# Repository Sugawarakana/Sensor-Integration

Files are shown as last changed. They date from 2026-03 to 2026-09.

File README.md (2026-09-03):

# Integrated Sensor Board for Battery Off-Gas Monitoring

A compact PCB and firmware stack that integrates multiple gas sensors and a battery off-gas detector onto one board, developed as part of a collaborative research project between the **University of Michigan**, **Universitat Politecnica Valencia**, and **UL Research Institutes**. The board targets applications in **battery safety**, **robotics**, and **energy storage system** environments where real-time multi-gas monitoring in constrained spaces is critical.

## Project Overview

The board consolidates multiple commerically-available gas sensors that detect hydrogen (H₂), carbon monoxide (CO), carbon dioxide (CO₂), volatile organic compounds (VOC), methane (CH₄), and electrolyte-vapor onto a single PCB, interfacing through **two independent CAN buses**, **I²C**, and an **analog ADC** channel. The controller is an **STM32 Nucleo-G431KB**, chosen for its native FDCAN peripheral, I²C support, and 12-bit ADC.

Since the Nucleo-G431KB has only one CAN controller, the two buses run at different bit rates on different hardware:

- **FDCAN1 @ 500 kbps** — Telaire T3650 and SGX-BLD2, through an on-board CAN transceiver.
- **MCP2515 @ 250 kbps** (SPI) — Li-ion Tamer, which requires its own 250 kbps segment.

The project spans: **PCB design** (Autodesk Eagle), **embedded firmware** ([OffgasMonitor.ino](OffgasMonitor/OffgasMonitor.ino), with non-blocking dual-CAN, dual-sensor I²C and ADC acquisition, byte-level protocol decoding, and on-chip health monitoring), and a **Python data-acquisition pipeline** ([serial_logger.py](OffgasMonitor/serial_logger.py), with serial parsing into a wide-table CSV).

## Specifications

| Parameter | Detail |
|---|---|
| **Controller** | STM32 Nucleo-G431KB (ARM Cortex-M4) |
| **Layers** | 1-layer PCB |
| **Board Thickness** | 1.6 mm (JLCPCB default) |
| **Power Supply** | 12 V battery input via terminal blocks |
| **Communication** | FDCAN1 (500 kbps), MCP2515 CAN (250 kbps) over SPI, I²C (100 kHz), analog ADC |
| **Log Rate** | 1 Hz (`LOG_INTERVAL = 1000 ms`) |
| **Serial** | 115200 baud |
| **Fabrication** | JLCPCB |

## Sensor Summary

| Sensor | Measurement | Interface | Address / ID | Power |
|---|---|---|---|---|
| Telaire T3650 | H₂, pressure, humidity, temperature | FDCAN1 @ 500 kbps | `0x18FF0CEB` (J1939, ext.) | 12 V direct |
| SGX-BLD2 | H₂ %, CO level, status flags | FDCAN1 @ 500 kbps | `0x256` (standard) | 12 V direct |
| Li-ion Tamer | Electrolyte-vapor off-gas, state, temperature | CAN @ 250 kbps via MCP2515 (SPI) | PGN `0xFF01` (J1939, ext.) | 12 V direct |
| MiCS-VZ-89TE | CO₂-equivalent & VOC | I²C | — | 3.3 V (Nucleo output) |
| MP7227 | CH₄ (methane) | Analog → ADC (`A0`) | — | 3.0 V (MIC5233 LDO) |
| SEN66 | PM1.0/2.5/4.0/10, RH, T, VOC & NOx index, NDIR CO₂ | I²C @ 100 kHz | `0x6B` | 3.3 V (buck from 12 V) |

> **Note:** the MiCS-VZ-89TE CO₂ figure is a CO₂-*equivalent* derived from its VOC channel, not a real CO₂ measurement. The SEN66 carries the true NDIR CO₂ reading; both are logged side by side (`co2_ppm` vs `sen66_co2_ppm`).

## Power Architecture

```
12V Supply
  │
  ├──[Terminal Blocks]──► Telaire T3650 (H₂)      — 12V direct
  ├──[Terminal Blocks]──► SGX-BLD2 (CO/H₂)        — 12V direct
  ├──[CAN Terminal]─────► Li-ion Tamer (off-gas)  — 12V direct
  │
  ├──► Buck regulator ──► 3.3V ──► SEN66 (PM/RH/T/VOC/NOx/CO₂)
  │
  └──► Buck regulator ──► 5V ──► Nucleo-G431KB (onboard regulator)
                                  └──► 3.3V ──► MiCS-VZ-89TE (CO₂ & VOC)
                                  └──► 3.3V ──► MIC5233 LDO ──► 3.0V ──► MP7227 (CH₄)
```

The SEN66 runs from its own buck rail rather than the Nucleo's 3.3 V output: its fan and
heater draw far more than the on-board regulator can supply. Only its I²C lines and ground
are shared with the MCU.

## Signal Chain

- **Telaire T3650 & SGX-BLD2:** CAN → on-board transceiver → **FDCAN1 @ 500 kbps** → MCU.
- **Li-ion Tamer:** CAN @ **250 kbps** → **MCP2515** controller → **SPI1** → MCU.
- **MiCS-VZ-89TE:** **I²C** directly to the MCU.
- **SEN66:** **I²C** to the MCU, sharing the bus with the MiCS-VZ-89TE. The bus is clamped to **100 kHz** (`Wire.setClock(100000)`) — that is the SEN66's ceiling, and the MiCS is comfortable at that rate.
- **MP7227 (CH₄):** analog output → zeroed via potentiometer → amplified (ADA4528 precision op-amp stage with HF filtering) → **ADC** (`A0`, 12-bit). Sensor rail from the **MIC5233** LDO.

### Li-ion Tamer → Power / CAN bus

| Li-ion Tamer pin | Connects to | Target terminal | Notes |
|---|---|---|---|
| Vin | PCB | 12 V (CAN terminal) | Supply positive |
| GND | PCB | GND (CAN terminal) | Supply / common ground |
| CANH | MCP2515 module | CANH | CAN differential high |
| CANL | MCP2515 module | CANL | CAN differential low |

### MCP2515 → Nucleo (SPI)

| MCP2515 pin | Nucleo pin | Type | Notes |
|---|---|---|---|
| SCK (18) | `PB3` / D13 | SPI clock | SPI1 default |
| MOSI (19) | `PB5` / D11 | Master out, slave in | SPI1 default |
| MISO (16) | `PB4` / D12 | Master in, slave out | SPI1 default |
| CS (20) | `PA8` / **D9** | Chip select | D9 instead of the default D10, which is `fdcan1_rx` |
| INT (21) | `PB0` / **D3** | Interrupt input | D3 instead of the default D2, which is `fdcan1_tx` |
| VCC / GND | 3V3 / GND | Power | Shared ground with the CAN terminal ground |
| RST | NRST | Reset | Pull-up reset |
| — | CAN ground | Power | GND (CAN terminal) |

The MCP2515 module runs from a **16 MHz** crystal (`QUARTZ_FREQUENCY`); the firmware prints whether the requested 250 kbps is an exact bit rate at boot.

## Design Highlights

- **Sensor placement:** all gas inlets sit along the board edges to maximize exposure and airflow.
- **Unidirectional signal flow:** voltage and signal routing follows a single direction across the board for a clean layout and easy debugging.
- **Ground stability:** a large copper pour provides a solid ground plane and minimizes ground bounce.
- **Filtering:** decoupling capacitors and filtering suppress high-frequency noise on power and signal lines.
- **Differential pair integrity:** CANH/CANL pairs are routed with controlled impedance and matched length.
- **Mechanical:** mounting holes for integration into enclosures or test fixtures.

## Firmware — `OffgasMonitor/OffgasMonitor.ino`

A single non-blocking acquisition loop that services two CAN buses, two I²C sensors, and the ADC, then emits one human-readable report per second.

### Architecture

- **Continuous CAN polling.** `pollAllCan()` drains both receive FIFOs completely on every loop iteration, so neither bus backs up while the report is being printed. It is called again immediately after `logData()` to catch frames that arrived during printing.
- **Non-blocking SEN66 startup.** `setup()` only issues the `deviceReset()`; the 1.2 s settling time, the `startContinuousMeasurement()` call, and the 1.1 s first-frame delay are stepped through by a `SEN66_RESET → SEN66_WAIT → SEN66_RUN` state machine inside `pollSen66()`, so no `delay()` ever stalls the CAN buses. A failed start is simply retried on the next 1.2 s tick.
- **Drift-free I²C sampling.** In `SEN66_RUN` the read deadline advances by a fixed `SEN66_PERIOD_MS` rather than reloading from `millis()`, so the sampling instant does not creep with the ~100 ms `logData()` spends on serial output; it resyncs only if it falls more than a full period behind. One read is ~2–3 ms of bus traffic at 100 kHz — short enough for the 32-slot FDCAN FIFO and the interrupt-driven MCP2515 buffer to absorb whatever arrives meanwhile.
- **Latest-frame slots.** Each CAN device gets a `Latest<T>` slot holding the most recent frame of the current cycle plus a `valid` flag. The flag is cleared after every report, so **a device that stays silent for a second leaves its section out of the output entirely** — silence is preserved as a diagnostic rather than being masked by stale data.
- **Age-based staleness for the SEN66.** The SEN66 deliberately does *not* use a `Latest<>` slot. It produces exactly one frame per second — the same rate as the log cycle — so a clear-every-cycle flag would make its block blink in and out as the two 1 Hz clocks drift past each other. Instead the last sample is kept with its `millis()` timestamp and reported with a `STALE` status once it ages past `SEN66_STALE_MS` (2.5 s), which points at I²C or power rather than at normal jitter.
- **CAN polling during ADC averaging.** `readAvgPolled()` averages 16 ADC samples to suppress noise; the ~200 µs settling gap between samples is spent polling CAN instead of idling. Averaging 16 samples across 2 channels takes ≈ 6.4 ms, which is too long to leave the buses unattended.
- **Rollover-safe scheduling.** The 1 Hz cadence uses a signed `millis()` comparison against `g_nextLog`, so it survives the 49-day `millis()` rollover, and the deadline advances by a fixed `LOG_INTERVAL` rather than from "now" to avoid drift.
- **Boot markers.** Setup prints tagged progress lines `A: boot` → `G: setup done` (`A` serial, `B` FDCAN1, `C` MCP2515, `D` I²C/ADC, `E` SEN66 reset + serial number, `F` die-temp calibration constants, `G` done), giving both a human and the Python logger an unambiguous reboot marker.

### Decoding

- **SGX-BLD2 (`0x256`)** — temperature (offset −55 °C), H₂ % (16-bit, ×0.01), an 8-bit status byte decoded bit-by-bit into named faults, supply voltage, humidity, roll counter, and CO level.
- **Telaire T3650 (`0x18FF0CEB`)** — pressure (16-bit LE, ×0.0078125 − 250 kPa), humidity (×0.4 %), H₂ concentration (×0.0025 %), temperature (×0.03125 − 273 °C), and a raw status byte.
- **Li-ion Tamer (PGN `0xFF01`)** — J1939 source address from the low ID byte, state (`Illegal / Error / Warmup / Normal / Alarm`), signed temperature, and a signed 16-bit off-gas scalar (÷100). The report is annotated `<<< ALARM` in the Alarm state, or flagged when the scalar reaches the alarm trigger level of 1.0.
- **SEN66 (I²C `0x6B`)** — PM1.0 / PM2.5 / PM4.0 / PM10 (µg/m³), relative humidity, temperature, VOC index, NOx index, and NDIR CO₂, read through the Sensirion float API.
- **Unknown frames** on either bus are captured and printed with bus name, ID, and raw data bytes, so an unexpected node on the wire is visible instead of silently dropped.

### SEN66 "unknown value" handling

The Sensirion float API divides each raw 16-bit word by its scale factor, so an unavailable channel surfaces as a plausible-looking number rather than `NaN`: `0xFFFF / 10 = 6553.5` for PM, `0x7FFF / 100 = 327.67` for RH/T, `0x7FFF / 10 = 3276.7` for the gas indices, and `0xFFFF` for CO₂. `printSen66Value()` compares against those sentinels and prints **`n/a`**, so a dead channel can never be mistaken for a real 6553.5 µg/m³ or 3276.7 index reading. Two status lines qualify the block further:

| Line | Meaning |
|---|---|
| `SEN66: no valid frame yet (starting up / running)` | Printed instead of the whole block; no frame has ever been read |
| `SEN66 Status:  gas index warming up` | VOC or NOx index still reads a hard 0 — VOC settles toward 100 over tens of seconds, NOx toward 1 after ~10–15 s |
| `SEN66 Status:  STALE, frame age <n> ms` | The cached frame is older than 2.5 s — check I²C wiring and the 3.3 V buck rail |

### Board health monitoring

Each cycle also reports the MCU's own condition using the internal channels and STM32G4 factory calibration constants:

1. **Actual VDDA** is back-computed from the internal reference (`VREFINT_CAL` at 3.0 V) — the reference voltage is fixed, so a lower reading implies a higher supply.
2. **Junction temperature (Tj)** is derived by normalizing the temperature-sensor reading to the 3.0 V calibration reference and interpolating between the factory `TS_CAL1` (30 °C) and `TS_CAL2` (130 °C) points.
3. Running **max Tj** and **min VDDA** are tracked across the whole run, and the status line reports `OK` / `HIGH` (> 60 °C) / `OVERHEAT` (> 85 °C).

Tj is die temperature, not ambient, and factory calibration is only accurate to roughly ±5 °C — it is a "is the board cooking?" check, not an ambient-temperature log.

### Serial output format

One block per second, sections separated by `=============================`. Each round begins with `Raw ADC Value:`, which the Python logger uses as the round boundary:

```
Raw ADC Value: 2048
Voltage: 1.650 V
=============================
Board health (STM32G431KB):
Die Temp:           42.3 C
Die Temp Max:       44.1 C
VDDA:               3298 mV
VDDA Min:           3290 mV
ADC raw (ts/vref):  1035/1512
Board Status:       OK
=============================
CO2 equ(ppm): 412 ppm
VOC(isobutylene) equ: 87 ppb
=============================
Message received from SEN66:
PM1.0:              0.0 ug/m3
PM2.5:              0.0 ug/m3
PM4.0:              0.0 ug/m3
PM10:               0.0 ug/m3
Humidity:           54.5 %
Temperature:        25.38 C
VOC Index:          0.0
NOx Index:          0.0
CO2:                431 ppm
SEN66 Status:       gas index warming up
=============================
Message received from SGX-BLD2:
...
=============================
Message received from Telaire T3650:
...
=============================
Message received from Li-ion Tamer:
Tamer SA=0xEB  State=Normal  Temp=24C  OffGas=0.12
=============================
```

## Host Data Acquisition — `OffgasMonitor/serial_logger.py`

A dependency-light (`pyserial` only) logger that parses the live serial stream and aggregates each one-second round into a single wide-table CSV row.

```bash
pip install pyserial

python serial_logger.py                 # use the PORT default in the file (COM3)
python serial_logger.py COM3            # specify the port
python serial_logger.py /dev/ttyACM0
python serial_logger.py --list-ports    # list available ports
python serial_logger.py --auto          # auto-pick a port that looks like an STM32
python serial_logger.py --selftest      # no hardware needed; verify parsing on built-in samples
```

| Flag | Effect |
|---|---|
| `--baud` | Baud rate (default 115200) |
| `--prefix` | Output filename prefix (default `sensor_log`; the start time is appended) |
| `--auto` | Pick the STMicroelectronics VID/description port automatically |
| `--list-ports` | List ports and exit |
| `--no-raw` | Skip the timestamped raw-text `.log` alongside the CSV |
| `--no-reconnect` | Exit on a dropout instead of retrying every 2 s |
| `--quiet` | Do not echo each row to the console |
| `--selftest` | Run the parser over built-in samples and check every field |

### Behavior

- **Section state machine.** The firmware reuses labels across sections (`Voltage:` appears under both ADC and SGX; `Temperature:` / `Humidity:` under SGX, Telaire *and* SEN66), so the parser disambiguates by *which section it is currently in*; a separator line clears the section and prevents bleed-over. Two label collisions are handled explicitly: `VOC(` anchors the MiCS reading so the SEN66's `VOC Index:` cannot overwrite it, and the colon in `SEN66:` distinguishes the no-frame one-liner from the in-block `SEN66 Status:` line.
- **Numbers are read after the last colon.** `num()` only searches the tail of a line, so digits inside a label — the 2 in `CO2`/`H2`, the 1.0 in `PM1.0` — are never mistaken for the reading. A channel printed `n/a` contains no digits and therefore lands as an empty cell.
- **Empty means silent.** ADC, board health, and I²C columns are populated every round. If one of the CAN devices sent nothing that second, its columns are left **empty on purpose** — that emptiness is the record that the device was offline, so it must not be forward-filled in post-processing. The `can_device` column lists which devices were heard from that round.
- **Empty SEN66 columns mean something else.** Because the SEN66 is on I²C, its block is present every round once running, so blank value columns are a fault rather than a silent bus. `sen66_status` says which: `NO_FRAME` (not started yet), `WARMUP` (gas-index algorithm not converged), or `STALE` with `sen66_age_ms` giving the age of the cached frame. Statuses accumulate semicolon-separated, since the firmware can print more than one in a round.
- **Fault flags reassembled.** Individual SGX flag lines are collected into a semicolon-separated `sgx_flags` list *and* re-packed into `sgx_flags_hex` for easy comparison.
- **Crash-safe.** Every row is flushed to disk immediately, a Ctrl+C or serial dropout still writes the in-progress round, the port is reconnected automatically after a dropout, and board reboots (`A: boot`) are counted and reported at exit.
- **Self-test.** `--selftest` runs the parser against embedded sample output covering the normal case, an overheat + fault-flag + Tamer-alarm case, a stale SEN66 frame with an `n/a` CO₂ channel, unknown frames on both buses, and a truncated final round holding only the SEN66 no-frame one-liner — then writes `selftest_output.csv`. It needs no hardware and not even `pyserial`.

### CSV columns

| Group | Columns |
|---|---|
| Timestamp | `date`, `time` |
| ADC (A0 / CH₄) | `raw_adc`, `voltage_adc` |
| Board health | `die_temp_c`, `die_temp_max_c`, `vdda_mv`, `vdda_min_mv`, `adc_raw_ts`, `adc_raw_vref`, `board_status` |
| MiCS-VZ-89TE | `co2_ppm`, `voc_ppb` |
| SEN66 | `sen66_pm1`, `sen66_pm25`, `sen66_pm4`, `sen66_pm10`, `sen66_rh_pct`, `sen66_temp_c`, `sen66_voc_index`, `sen66_nox_index`, `sen66_co2_ppm`, `sen66_status`, `sen66_age_ms` |
| Devices heard | `can_device` |
| SGX-BLD2 | `sgx_temp_c`, `sgx_h2_pct`, `sgx_voltage_v`, `sgx_humidity_pct`, `sgx_roll_counter`, `sgx_level_co`, `sgx_flags`, `sgx_flags_hex` |
| Telaire T3650 | `tel_pressure_kpa`, `tel_humidity_pct`, `tel_h2_conc_pct`, `tel_temp_c`, `tel_status` |
| Li-ion Tamer | `tamer_sa`, `tamer_state`, `tamer_temp_c`, `tamer_offgas`, `tamer_alarm` |
| Unknown frames | `unk_fdcan_id`, `unk_fdcan_data`, `unk_mcp_id`, `unk_mcp_data` |

## Library Dependencies

| Library | Version | Purpose | Source |
|---|---|---|---|
| `ACANFD_STM32` — Pierre Molinaro | 1.1.2-rc1 | FDCAN1 @ 500 kbps (T3650, SGX-BLD2) | https://github.com/pierremolinaro/acanfd-stm32 |
| `ACAN2515` — Pierre Molinaro | 2.1.5 | MCP2515 CAN @ 250 kbps (Li-ion Tamer) | https://github.com/pierremolinaro/acan2515 |
| `MICS-VZ-89TE` — Herve Grabas | — | CO₂-equivalent & VOC over I²C | https://github.com/HGrabas/MICS-VZ-89TE |
| `arduino-i2c-sen66` — Sensirion (LeonieFierz) | — | SEN66 PM / RH / T / VOC / NOx / CO₂ over I²C | https://github.com/Sensirion/arduino-i2c-sen66 |

Board support: **STM32duino** (STM32 MCU based boards), target *Nucleo-32 / Nucleo G431KB*.

> **Build note:** the Sensirion driver and the STM32 core both define `NO_ERROR` with different values, so the sketch `#undef`s it and pins it to the Sensirion meaning (`0`) before any error check. If your `arduino-i2c-sen66` version declares `getSerialNumber(char *, uint16_t)`, drop the `(int8_t *)` cast in `setupSen66()`.

## Testing

The board was validated on an Agilent E3641A bench power supply at **12.00 V / 0.200 A**. Sensor data from all channels was streamed over USB serial and captured by the Python logger, confirming correct FDCAN, MCP2515 CAN, I²C, and ADC acquisition — real-time temperature, humidity, raw ADC values, off-gas state, and computed gas concentrations (ppm/ppb) from each module. The SEN66 draws its own 3.3 V buck rail, so the supply current rises accordingly once its fan spins up; budget for that when sizing the bench supply.

The logger's `--selftest` mode covers the whole parsing path without hardware — including the SEN66 warm-up, stale-frame, and `n/a`-channel cases — and exits non-zero on any field mismatch, so it doubles as a regression check after editing either the firmware's print strings or the parser.

## Repository Structure

| Path | Contents |
|---|---|
| [OffgasMonitor/OffgasMonitor.ino](OffgasMonitor/OffgasMonitor.ino) | Current firmware: dual CAN + I²C (MiCS-VZ-89TE, SEN66) + ADC + board health |
| [OffgasMonitor/serial_logger.py](OffgasMonitor/serial_logger.py) | Current host logger: serial → wide-table CSV |
| [schematic.pdf](schematic.pdf) / [pcb_layout.pdf](pcb_layout.pdf) | Full schematic and PCB layout (top view) |
| [guides/](guides/) | Sensor and component datasheets (T3650, SGX-BLD2, MiCS-VZ-89TE, MP7227, MIC5233, Li-ion Tamer, Nucleo-G431KB) |
| [Deprecated/PCB Design/](Deprecated/PCB%20Design/) | Autodesk Eagle sources (`.sch` / `.brd`) and JLCPCB Gerber/CAM output, by revision (3.11, 3.22, 5.1) |
| [Deprecated/modules/](Deprecated/modules/) | Superseded per-sensor firmware & logging sketches (CAN, CH₄/ADC, CO₂/I²C) |
| [Deprecated/sensor_read/](Deprecated/sensor_read/) | Superseded integrated firmware + pandas/Excel logger |

Everything under [Deprecated/](Deprecated/) is kept for reference only; the active firmware and logger live in [OffgasMonitor/](OffgasMonitor/).

## Tools & Skills

- **EDA:** Autodesk Eagle
- **Fabrication:** JLCPCB
- **Controller Platform:** STM32 Nucleo-G431KB (ARM Cortex-M4)
- **Firmware:** Arduino / STM32duino — `ACANFD_STM32` (FDCAN), `ACAN2515` (SPI CAN), `arduino-i2c-sen66` and `MICS-VZ-89TE` on a shared I²C bus, 12-bit ADC, on-chip Tj/VDDA calibration
- **Software:** Python (`pyserial`) for serial data acquisition & CSV logging
- **Skills demonstrated:** PCB design · multi-protocol embedded firmware (dual CAN / I²C / ADC) · J1939 & proprietary CAN frame decoding · non-blocking real-time acquisition · sensor data logging & diagnostics

## License

This project was developed under the University of Michigan and UL Research Institutes collaboration. Contact the author for usage permissions.

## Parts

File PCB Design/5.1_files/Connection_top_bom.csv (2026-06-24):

Comment | Designator | Footprint | JLC Part #
1.0uF | C10 | C0805 | C1712
1k | R1 R8 R9 | R0805 | C110774
2.2uF | C9 | C0603 | C1607
4.7 uF(elec) | C6 | C0603 | C1953079
4.7uF | C8 | C1206 | C1872
4k7 | R5 R6 | M1206 | C17936
6k49 | R | R0603 | C218127
10k | R3 R7 R11 | M1206 | C1489
49k9 | R2 R12 | R0603 | C218050
60R | R4 R10 | R0603 | C166918
100nF | C2 C3 C4 | C0402 | C1525
680nF | C7 | C1206 | C1881
3224W1203E | R13 | TRIM_3224W1203E
ADA4528-1ARMZ-R7 | U5 | SOP65P490X110-8N
MIC5233 | U$3 | MIC5233
MICS-VZ-89TE | U$4 | MICS-VZ-89TE_FP
MP7227 | U$1 | MP7227_FP
SN65HVD230 | U2 | SOIC127P599X175-8N

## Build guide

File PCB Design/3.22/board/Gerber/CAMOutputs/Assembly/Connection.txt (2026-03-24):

Partlist exported from C:/Users/Homura/Desktop/3.18/3.22/board/Connection.sch at 2026/3/23 12:09

Qty Value            Device           Package              Parts                                                                Description               AVAILABILITY CHECK_PRICES                                                                      DESCRIPTION                                                                                                                                                                              MF                 MP               MPN OC_FARNELL OC_NEWARK PACKAGE                  POPULARITY PRICE SNAPEDA_LINK                                                                       SPICEPREFIX
8                    1,6/0,8          1,6/0,8              12V_BOARD, 12V_CAN, CAN_H, CAN_H1, CAN_L, CAN_L1, GND_BOARD, GND_CAN THROUGH-HOLE PAD                                                                                                                                                                                                                                                                                                                                                                                        15                                                                                                             
4                    FE08-1           FE08                 SV1, SV2, SV3, SV4                                                   FEMALE HEADER                                                                                                                                                                                                                                                                                                                                             unknown    unknown                            10                                                                                                             
2   0.1μF            C2,5-3           C2.5-3               C2, C3                                                               CAPACITOR                                                                                                                                                                                                                                                                                                                                                                                               38                                                                                                             
1   1.0μF            C2,5-3           C2.5-3               C1                                                                   CAPACITOR                                                                                                                                                                                                                                                                                                                                                                                               38                                                                                                             
1   100-nF ceramic   C2,5-3           C2.5-3               C4                                                                   CAPACITOR                                                                                                                                                                                                                                                                                                                                                                                               38                                                                                                             
3   10000Ω           R-EU_0207/10     0207/10              R3, R7, R11                                                          RESISTOR, European symbol                                                                                                                                                                                                                                                                                                                                                                               81                                                                                                  R          
3   1000Ω            R-EU_0207/10     0207/10              R1, R8, R9                                                           RESISTOR, European symbol                                                                                                                                                                                                                                                                                                                                                                               81                                                                                                  R          
1   2.2μF            C2,5-3           C2.5-3               C5                                                                   CAPACITOR                                                                                                                                                                                                                                                                                                                                                                                               38                                                                                                             
1   3296W-1-203LF    3296W-1-203LF    TRIM_3296W-1-203LF   VR1                                                                  Check availability        In Stock     https://www.snapeda.com/parts/3296W-1-203LF/Bourns/view-part/?ref=eda                                                                   Trimmer, Cermet, Rest 20 Kilohms, PCB, 25 Turns, Pwr-Rtg 0.5W | Bourns 3296W-1-203LF                                               Bourns             3296W-1-203LF                             NON STANDARD-3 Bourns               None  https://www.snapeda.com/parts/3296W-1-203LF/Bourns/view-part/?ref=snap                        
1   4.7 uF           C2,5-3           C2.5-3               C6                                                                   CAPACITOR                                                                                                                                                                                                                                                                                                                                                                                               38                                                                                                             
1   4.7μF            C2,5-3           C2.5-3               C8                                                                   CAPACITOR                                                                                                                                                                                                                                                                                                                                                                                               38                                                                                                             
2   4700             R-EU_0207/10     0207/10              R5, R6                                                               RESISTOR, European symbol                                                                                                                                                                                                                                                                                                                                                                               81                                                                                                  R          
2   49000Ω           R-EU_0207/10     0207/10              R2, R12                                                              RESISTOR, European symbol                                                                                                                                                                                                                                                                                                                                                                               81                                                                                                  R          
1   6.5kΩ            R-EU_0207/10     0207/10              R                                                                    RESISTOR, European symbol                                                                                                                                                                                                                                                                                                                                                                               81                                                                                                  R          
2   60Ω              R-EU_0207/10     0207/10              R4, R10                                                              RESISTOR, European symbol                                                                                                                                                                                                                                                                                                                                                                               81                                                                                                  R          
1   680nF            C2,5-3           C2.5-3               C7                                                                   CAPACITOR                                                                                                                                                                                                                                                                                                                                                                                               38                                                                                                             
1   ADA4528-1ARMZ-R7 ADA4528-1ARMZ-R7 SOP65P490X110-8N     U5                                                                   Check availability        In Stock     https://www.snapeda.com/parts/ADA4528-1ARMZ-R7/Analog+Devices/view-part/?ref=eda                                                        Precision, Ultralow Noise, RRIO, Zero-Drift Single Op Amp                                                                          Analog Devices     ADA4528-1ARMZ-R7                          MSOP-8 Analog Devices               None  https://www.snapeda.com/parts/ADA4528-1ARMZ-R7/Analog+Devices/view-part/?ref=snap             
1   MIC5233-3PIN     MIC5233-3PIN     SOT230P700X180-4N    U$2                                                                                                                                                                                                                                                                                                                                                                                                                                                                                                                                                                                         
1   MICS-VZ-89TE     MICS-VZ-89TE     MICS-VZ-89TE_FP      U$4                                                                                                                                                                                                                                                                                                                                                                                                                                                                                                                                                                                         
1   MP7227           MP7227           MP7227_FP            U$1                                                                                                                                                                                                                                                                                                                                                                                                                                                                                                                                                                                         
1   NUCLEO-G431KB    NUCLEO-G431KB    MODULE_NUCLEO-G431KB U1                                                                   Check availability        In Stock     https://www.snapeda.com/parts/NUCLEO-G431KB/STMicroelectronics/view-part/?ref=eda                                                       STM32G431 Nucleo-32 STM32G4 ARM® Cortex®-M4 MCU 32-Bit Embedded Evaluation Board                                                   STMicroelectronics NUCLEO-G431KB                             None                                None  https://www.snapeda.com/parts/NUCLEO-G431KB/STMicroelectronics/view-part/?ref=snap            
1   SN65HVD230       SN65HVD230       SOIC127P599X175-8N   U2                                                                   Check availability        In Stock     https://www.snapeda.com/parts/SN65HVD230/Texas+Instruments/view-part/?ref=eda                                                           1/1 Transceiver Half CANbus 8-SOIC                                                                                                 Texas Instruments  SN65HVD230                                SOIC-8 Texas Instruments            None  https://www.snapeda.com/parts/SN65HVD230/Texas+Instruments/view-part/?ref=snap

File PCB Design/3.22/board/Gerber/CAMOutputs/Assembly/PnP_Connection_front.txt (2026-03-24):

U$2	22.86	31.75	0.00	MIC5233-3PIN	SOT230P700X180-4N
U2	29.21	48.26	90.00	SN65HVD230	SOIC127P599X175-8N
U5	77.47	7.62	0.00	ADA4528-1ARMZ-R7	SOP65P490X110-8N

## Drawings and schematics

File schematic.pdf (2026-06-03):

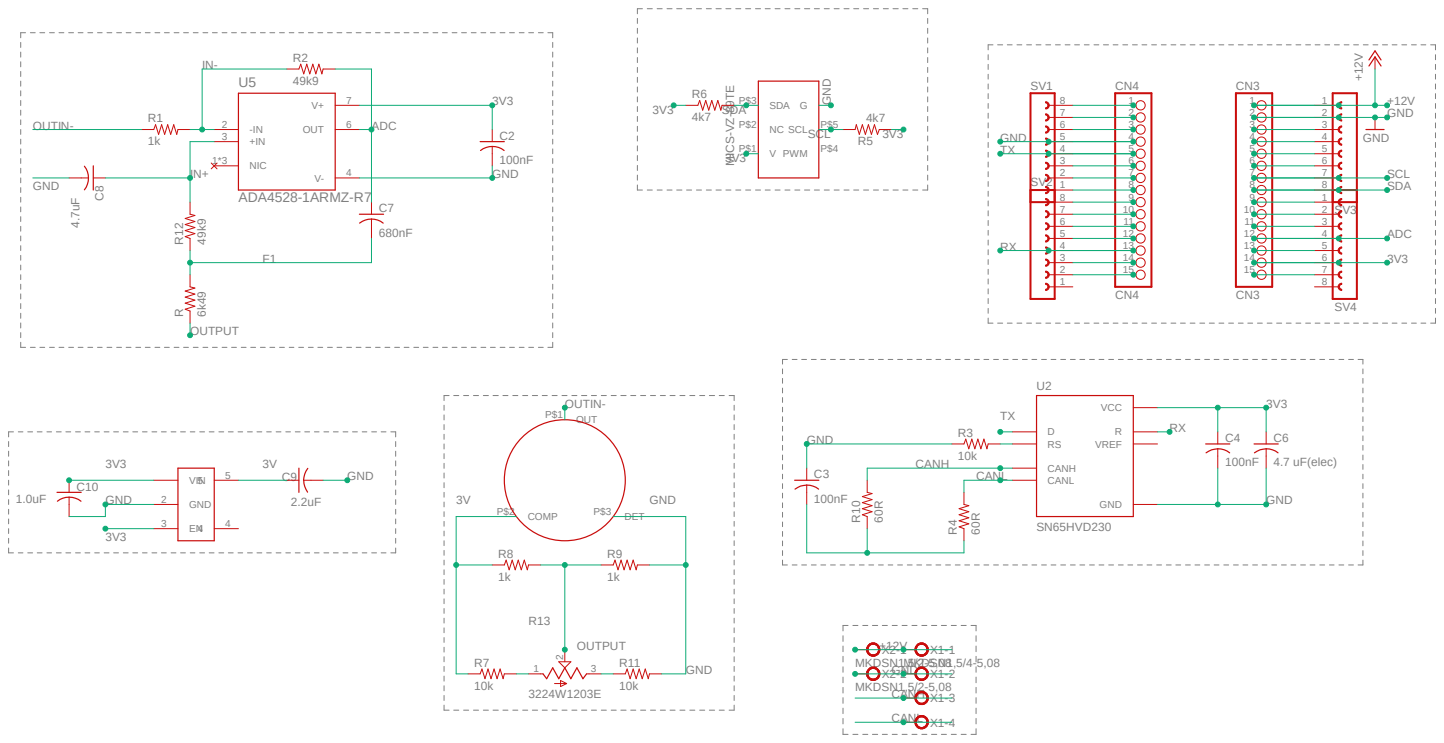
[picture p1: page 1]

10 11 12 13 14

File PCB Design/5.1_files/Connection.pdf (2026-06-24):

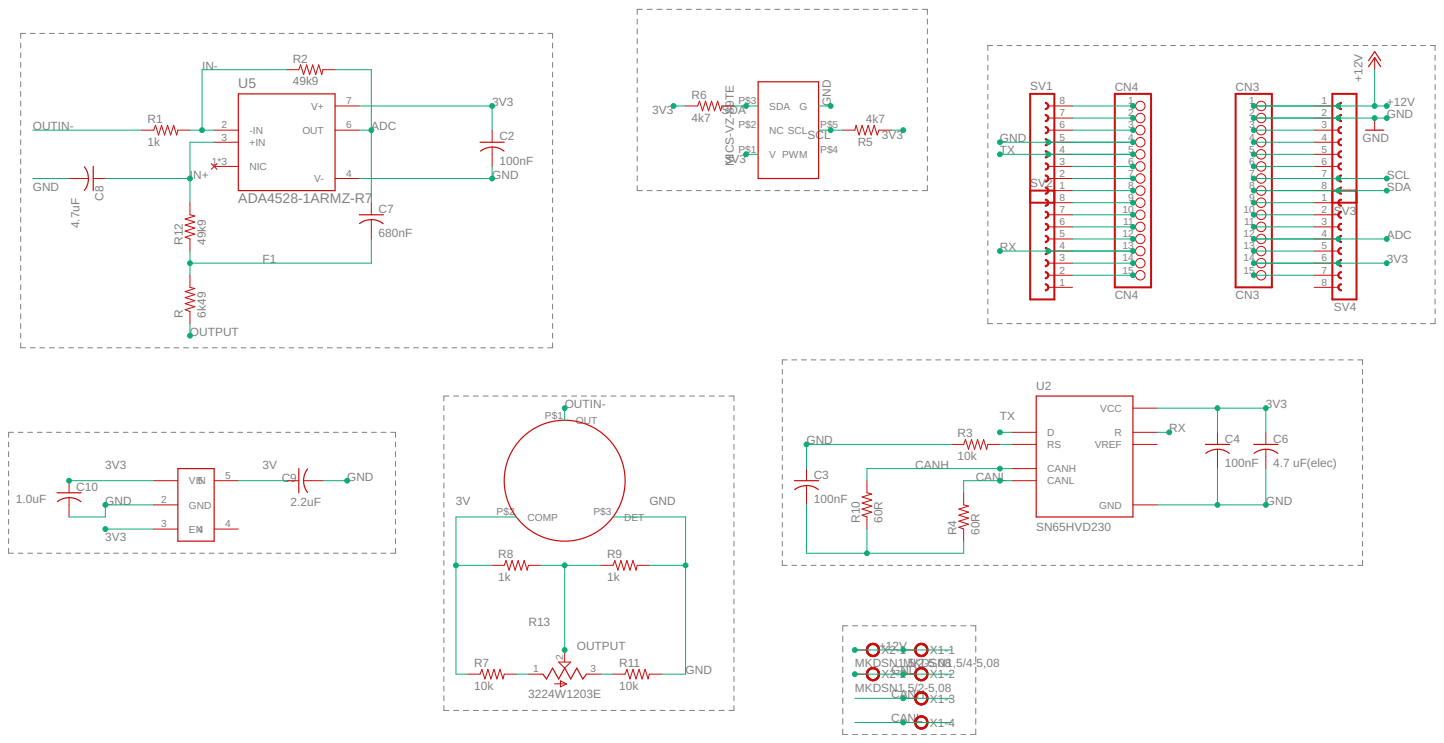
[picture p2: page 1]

10 11 12 13 14 15

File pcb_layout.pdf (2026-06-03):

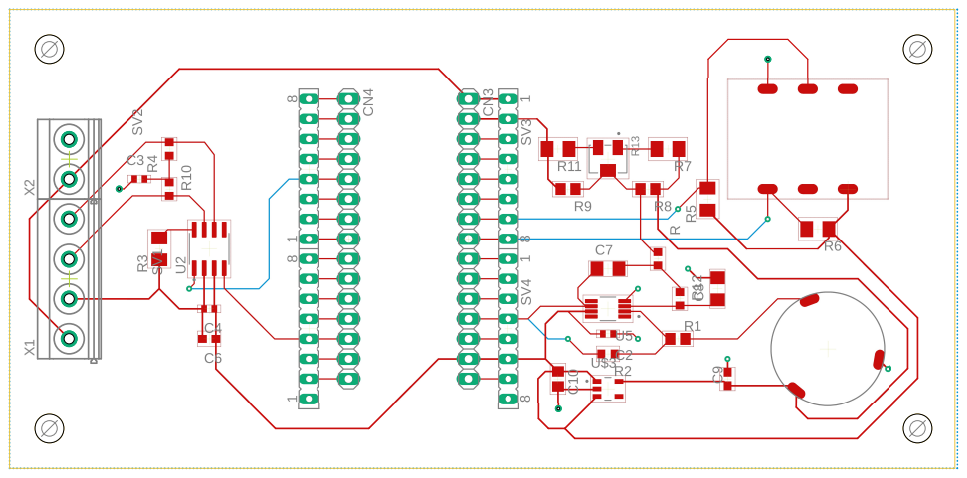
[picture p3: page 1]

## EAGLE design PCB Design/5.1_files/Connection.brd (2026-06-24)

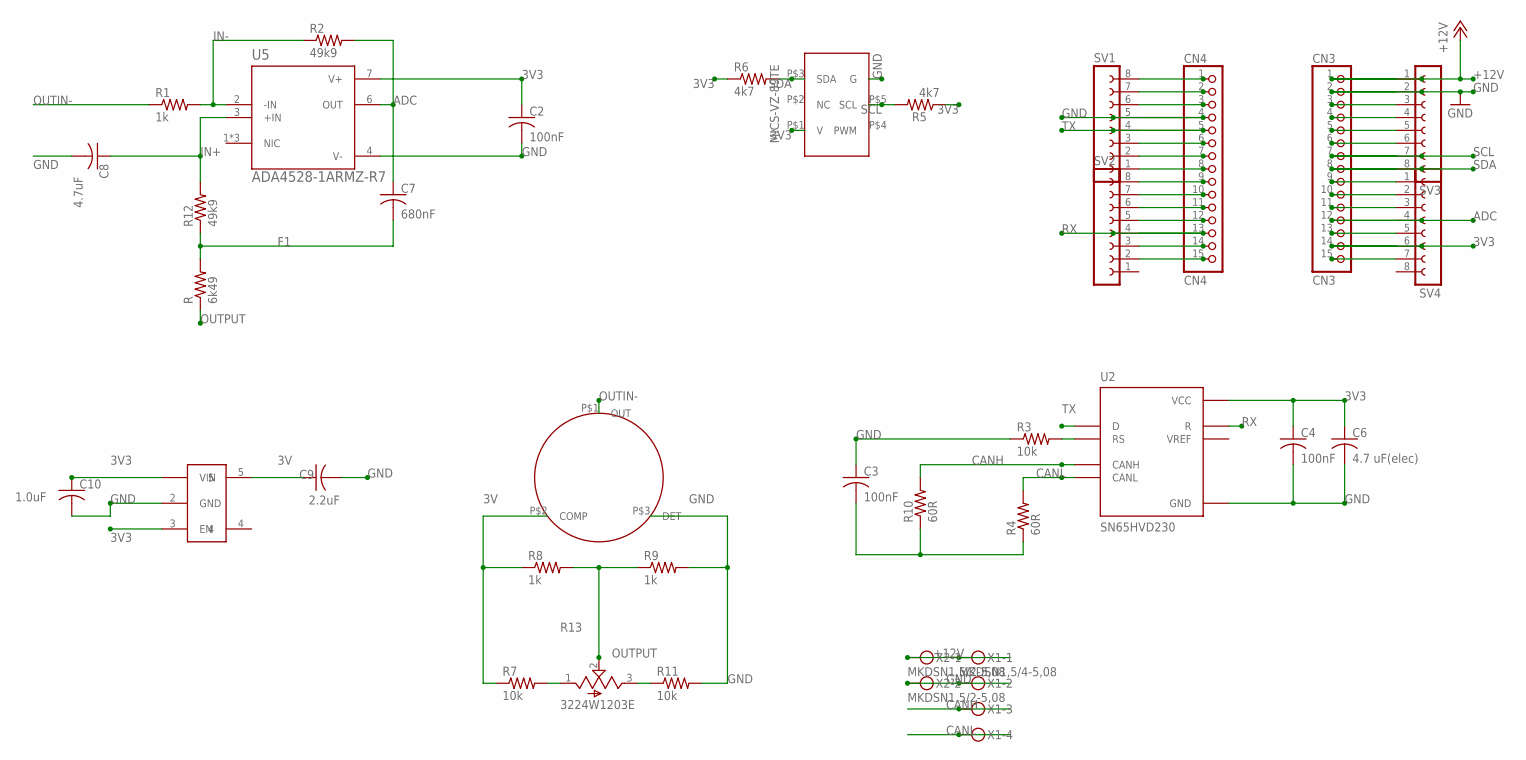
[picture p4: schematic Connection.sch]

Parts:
C2, C3, C4: 100nF; C0402
C6: 4.7 uF(elec); C0603
C7: 680nF; C1206
C8: 4.7uF; C1206
C9: 2.2uF; C0603
C10: 1.0uF; C0805
CN3: CN3; 1X15
CN4: CN4; 1X15
R: 6k49; R0603
R1, R8, R9: 1k; R0805
R2, R12: 49k9; R0603
R3, R7, R11: 10k; M1206
R4, R10: 60R; R0603
R5, R6: 4k7; M1206
R13: 3224W1203E; TRIM_3224W1203E
SV1, SV2, SV3, SV4: FE08-1; FE08
U2: SN65HVD230; SOIC127P599X175-8N
U5: ADA4528-1ARMZ-R7; SOP65P490X110-8N
U$1: MP7227; MP7227_FP
U$3: MIC5233
U$4: MICS-VZ-89TE; MICS-VZ-89TE_FP
X1: MKDSN1,5/4-5,08
X2: MKDSN1,5/2-5,08

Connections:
3V: C9.1, R7.1, R8.1, U$1.P$2 (COMP), U$3.5
3V3: C2.1, C4.1, C6.1, C10.1, CN3.14, R5.1, R6.1, SV4.6, U2.3 (VCC), U5.7 (V+), U$3.1 (VIN), U$3.3 (EN), U$4.P$1 (V)
+12V: CN3.1, SV3.1, X1.1, X2.1
ADC: C7.1, CN3.12, R2.2, SV4.4, U5.6 (OUT)
C1: C3.2, R4.1, R10.1
CANH: R10.2, U2.7 (CANH), X1.3
CANL: R4.2, U2.6 (CANL), X1.4
F1: C7.2, R.2, R12.1
GND: C2.2, C3.1, C4.2, C6.2, C8.2, C9.2, C10.2, CN3.2, CN4.4, R3.1, R9.2, R11.2, SV1.5, SV3.2, U2.2 (GND), U5.4 (V-), U$1.P$3 (DET), U$3.2 (GND), U$4.P$6 (G), X1.2, X2.2
IN+: C8.1, R12.2, U5.3 (+IN)
IN-: R1.2, R2.1, U5.2 (-IN)
unnamed: CN3.6, SV3.6
unnamed: CN3.3, SV3.3
unnamed: CN3.4, SV3.4
unnamed: CN3.5, SV3.5
unnamed: CN3.9, SV4.1
unnamed: CN3.10, SV4.2
unnamed: CN3.11, SV4.3
unnamed: CN3.13, SV4.5
unnamed: CN3.15, SV4.7
unnamed: CN4.8, SV1.1
unnamed: CN4.7, SV1.2
unnamed: CN4.6, SV1.3
unnamed: CN4.3, SV1.6
unnamed: CN4.2, SV1.7
unnamed: CN4.1, SV1.8
unnamed: CN4.15, SV2.2
unnamed: CN4.14, SV2.3
unnamed: CN4.12, SV2.5
unnamed: CN4.11, SV2.6
unnamed: CN4.10, SV2.7
unnamed: CN4.9, SV2.8
OUTIN-: R1.1, U$1.P$1 (OUT)
OUTPUT: R.1, R8.2, R9.1, R13.2
PL: R7.2, R13.1
PR: R11.1, R13.3
RS: R3.2, U2.8 (RS)
RX: CN4.13, SV2.4, U2.4 (R)
SCL: CN3.7, R5.2, SV3.7, U$4.P$5 (SCL)
SDA: CN3.8, R6.2, SV3.8, U$4.P$3 (SDA)
TX: CN4.5, SV1.4, U2.1 (D)

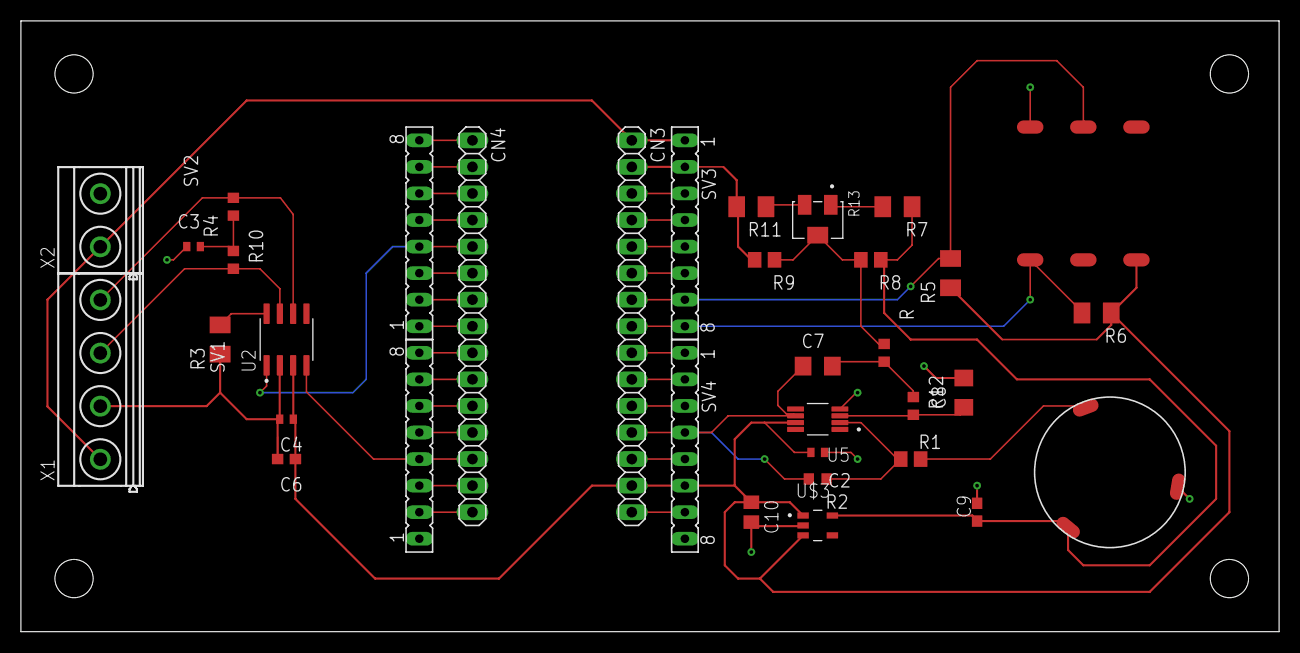
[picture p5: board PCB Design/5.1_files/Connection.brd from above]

Board: 2 copper layers, 120.3 x 58.4 mm, 35 parts (0 on the bottom side), 41 nets.

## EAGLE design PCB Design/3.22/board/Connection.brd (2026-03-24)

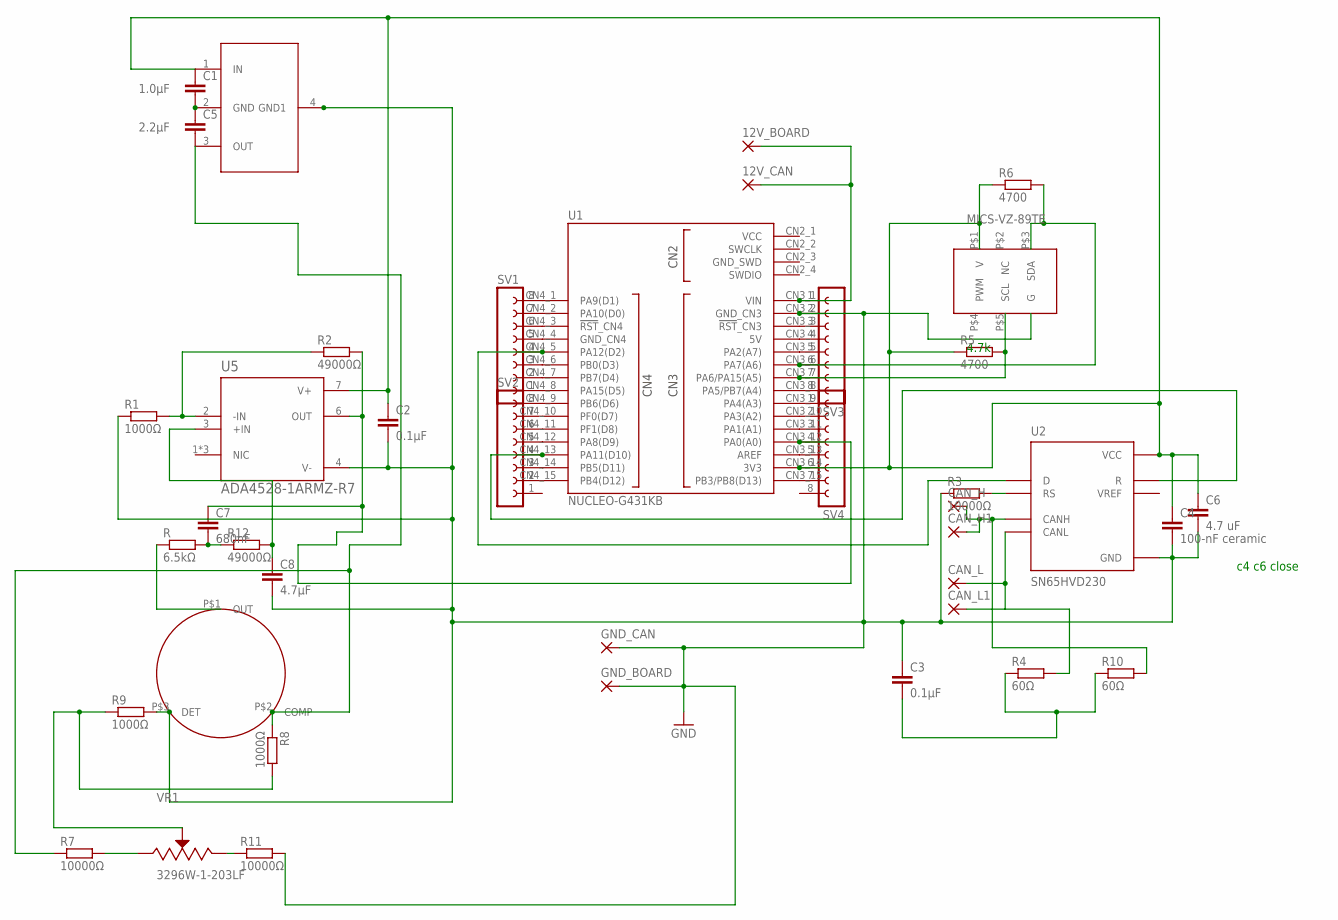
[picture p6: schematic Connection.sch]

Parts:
12V_BOARD, 12V_CAN: 1,6/0,8
C1: 1.0μF; C2.5-3
C2, C3: 0.1μF; C2.5-3
C4: 100-nF ceramic; C2.5-3
C5: 2.2μF; C2.5-3
C6: 4.7 uF; C2.5-3
C7: 680nF; C2.5-3
C8: 4.7μF; C2.5-3
CAN_H, CAN_H1: 1,6/0,8
CAN_L, CAN_L1: 1,6/0,8
GND_BOARD: 1,6/0,8
GND_CAN: 1,6/0,8
R: 6.5kΩ; 0207/10
R1, R8, R9: 1000Ω; 0207/10
R2, R12: 49000Ω; 0207/10
R3, R7, R11: 10000Ω; 0207/10
R4, R10: 60Ω; 0207/10
R5, R6: 4700; 0207/10
SV1, SV2, SV3, SV4: FE08-1; FE08
U1: NUCLEO-G431KB; MODULE_NUCLEO-G431KB
U2: SN65HVD230; SOIC127P599X175-8N
U5: ADA4528-1ARMZ-R7; SOP65P490X110-8N
U$1: MP7227; MP7227_FP
U$2: MIC5233-3PIN; SOT230P700X180-4N
U$4: MICS-VZ-89TE; MICS-VZ-89TE_FP
VR1: 3296W-1-203LF; TRIM_3296W-1-203LF

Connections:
GND: C2.2, C3.1, C4.2, C6.2, C8.2, GND_BOARD.1, GND_CAN.1, R1.1, R3.1, R9.2, R11.2, SV3.2, U1.CN3_2 (GND_CN3), U2.2 (GND), U5.4 (V-), U$1.P$3 (DET), U$4.P$6 (G)
GND_SWD: U1.CN2_3 (GND_SWD)
unnamed: 12V_BOARD.1, 12V_CAN.1, SV3.1, U1.CN3_1 (VIN)
unnamed: R5.2, SV3.7, U1.CN3_7 (PA6/PA15(A5)), U$4.P$5 (SCL)
unnamed: R6.2, SV3.6, U1.CN3_6 (PA7(A6)), U$4.P$3 (SDA)
unnamed: R1.2, R2.1, U5.2 (-IN)
unnamed: R.1, U$1.P$1 (OUT)
unnamed: CAN_H.1, CAN_H1.1, R10.2, U2.7 (CANH)
unnamed: CAN_L.1, CAN_L1.1, R4.2, U2.6 (CANL)
unnamed: C1.1, C2.1, C4.1, C6.1, R5.1, R6.1, SV4.6, U1.CN3_14 (3V3), U2.3 (VCC), U5.7 (V+), U$2.1 (IN), U$4.P$1 (V)
unnamed: SV1.4, U1.CN4_5 (PA12(D2)), U2.1 (D)
unnamed: SV2.4, U1.CN4_13 (PA11(D10)), U2.4 (R)
unnamed: R3.2, U2.8 (RS)
unnamed: C3.2, R4.1, R10.1
unnamed: C7.1, R2.2, SV4.4, U1.CN3_12 (PA0(A0)), U5.6 (OUT)
unnamed: C5.1, U$2.2 (GND)
unnamed: R8.2, R9.1, VR1.2 (WIPER)
unnamed: C7.2, R.2, R12.1
unnamed: C5.2, R7.1, R8.1, U$1.P$2 (COMP), U$2.3 (OUT)
unnamed: SV3.3, U1.CN3_3 (!RST!_CN3)
unnamed: SV3.4, U1.CN3_4 (5V)
unnamed: SV3.5, U1.CN3_5 (PA2(A7))
unnamed: SV3.8, U1.CN3_8 (PA5/PB7(A4))
unnamed: SV4.1, U1.CN3_9 (PA4(A3))
unnamed: SV4.2, U1.CN3_10 (PA3(A2))
unnamed: SV4.3, U1.CN3_11 (PA1(A1))
unnamed: SV4.5, U1.CN3_13 (AREF)
unnamed: SV4.7, U1.CN3_15 (PB3/PB8(D13))
unnamed: SV1.1, U1.CN4_8 (PA15(D5))
unnamed: SV1.2, U1.CN4_7 (PB7(D4))
unnamed: SV1.3, U1.CN4_6 (PB0(D3))
unnamed: SV1.5, U1.CN4_4 (GND_CN4)
unnamed: SV1.6, U1.CN4_3 (!RST!_CN4)
unnamed: SV1.7, U1.CN4_2 (PA10(D0))
unnamed: SV1.8, U1.CN4_1 (PA9(D1))
unnamed: SV2.2, U1.CN4_15 (PB4(D12))
unnamed: SV2.3, U1.CN4_14 (PB5(D11))
unnamed: SV2.5, U1.CN4_12 (PA8(D9))
unnamed: SV2.6, U1.CN4_11 (PF1(D8))
unnamed: SV2.7, U1.CN4_10 (PF0(D7))
unnamed: SV2.8, U1.CN4_9 (PB6(D6))
unnamed: C1.2, U$2.4 (GND1)
unnamed: R7.2, VR1.1 (CCW)
unnamed: R11.1, VR1.3 (CW)
unnamed: C8.1, R12.2, U5.3 (+IN)
VCC: U1.CN2_1 (VCC)

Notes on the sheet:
4.7k
c4 c6 close

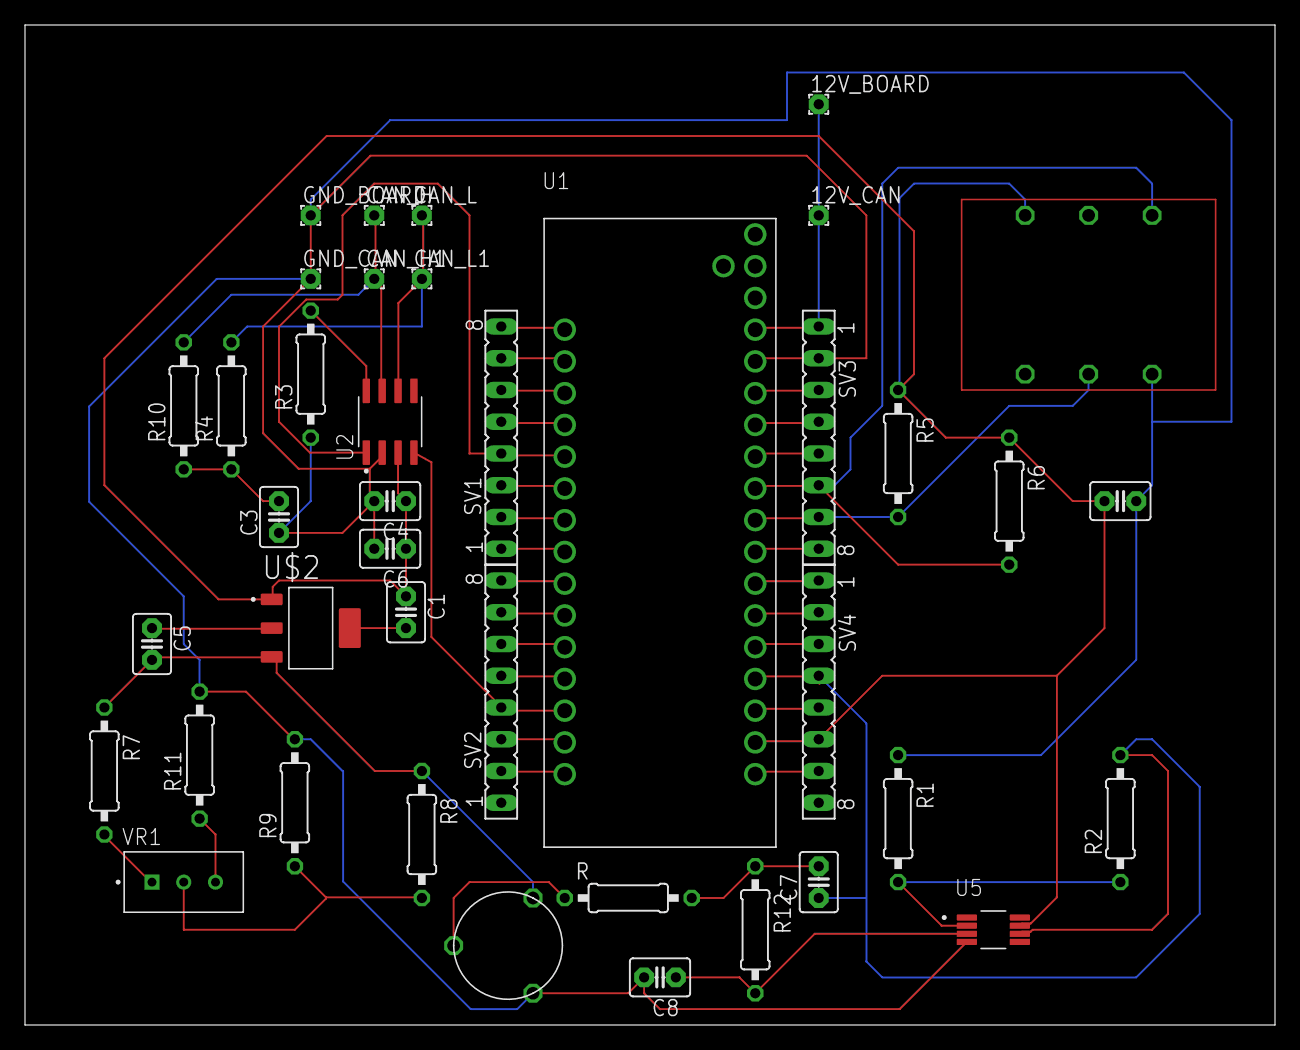
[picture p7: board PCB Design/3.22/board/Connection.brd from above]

Board: 2 copper layers, 100.0 x 80.0 mm, 40 parts (0 on the bottom side), 44 nets.

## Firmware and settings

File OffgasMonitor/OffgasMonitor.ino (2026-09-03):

#include <ACANFD_STM32.h>
#include <ACANFD_STM32_NUCLEO_G431KB-objects.h>
#include <ACANFD_STM32_CANFDMessage.h>
#include <Wire.h>
#include <MICS-VZ-89TE.h>
#include <ACAN2515.h>
#include <SensirionI2cSen66.h>

// The Sensirion driver and the STM32 core both define NO_ERROR; force the
// Sensirion meaning (0) so error checks below stay consistent.
#ifdef NO_ERROR
#undef NO_ERROR
#endif
#define NO_ERROR 0

// ======================= Settings =======================
static const byte MCP2515_CS  = PA8;   // D9 (default D10 used by fdcan1_rx)
static const byte MCP2515_INT = PB0;   // D3 (default D2 used by fdcan1_tx)
// SPI1: MOSI=PB5(D11), MISO=PB4(D12), SCK=PB3(D13) by default

static const uint32_t QUARTZ_FREQUENCY           = 16UL * 1000UL * 1000UL; // 16MHz
static const uint32_t CAN_BITRATE_TAMER          = 250UL * 1000UL; // 250kbps
static const uint32_t CAN_BITRATE_T3650_SGXBLD2  = 500UL * 1000UL; // 500kbps

static const int  ANALOG_IN_PIN = A0;             // ADC pin
static const unsigned long LOG_INTERVAL = 1000;   // ms

// CAN ID
static const uint32_t ID_SGX     = 0x256;         // SGX-BLD2, standard
static const uint32_t ID_TELAIRE = 0x18FF0CEB;    // T3650, J1939
static const uint32_t PGN_TAMER  = 0x00FF01;      // Li-ion Tamer, J1939

// ---- SEN66 (I2C, shares the bus with MICS-VZ-89TE) ----
// The bus must run at 100 kHz: that is the SEN66 ceiling, and the MICS accepts it too.
static const uint32_t SEN66_RESET_MS  = 1200;     // settling time after deviceReset()
static const uint32_t SEN66_WARMUP_MS = 1100;     // first frame is valid only after this
static const uint32_t SEN66_PERIOD_MS = 1000;     // measurement period is fixed at 1 s
static const uint32_t SEN66_STALE_MS  = 2500;     // beyond this the cached frame is flagged

// "Unknown value" sentinels. The float API divides the raw 16-bit words by their
// scale factor, so 0xFFFF / 0x7FFF surface as the constants below rather than NaN.
static const float    SEN66_PM_INVALID  = 6553.5f;   // 0xFFFF / 10
static const float    SEN66_RHT_INVALID =  327.67f;  // 0x7FFF / 100
static const float    SEN66_IDX_INVALID = 3276.7f;   // 0x7FFF / 10
static const uint16_t SEN66_CO2_INVALID = 0xFFFF;

// ---- Onboard Temp Detection ----
#if !defined(ATEMP) || !defined(AVREF)
#error "Board part number error"
#endif

// STM32G4 factory VDDA = 3.0 V / 12 bit ADC
#define TS_CAL1_ADDR      ((const uint16_t *)0x1FFF75A8UL)  //  30 °C
#define TS_CAL2_ADDR      ((const uint16_t *)0x1FFF75CAUL)  // 130 °C
#define VREFINT_CAL_ADDR  ((const uint16_t *)0x1FFF75AAUL)  // VREFINT @ 3.0 V

static const float   CAL_TEMP1 =   30.0f;
static const float   CAL_TEMP2 =  130.0f;
static const float   CAL_VDDA  = 3000.0f;   // mV
static const uint8_t N_AVG     = 16;
static const float   TJ_WARN   = 60.0f;     // °C
static const float   TJ_ALARM  = 85.0f;     // °C

// ======================= Objects =======================
SPIClass         canSPI(PB5, PB4, PB3);
ACAN2515         can(MCP2515_CS, canSPI, MCP2515_INT);
MICS_VZ_89TE     mics;
SensirionI2cSen66 sen66;

// ======================= Status =======================
// One slot per device: stores the latest frame of the current cycle, overwriting previous data.
// The 'valid' flag indicates receipt during the current recording cycle and is cleared after logData() executes;
// thus, if a device fails to transmit during a given second, the corresponding entry is missing,
// preserving the diagnostic value regarding the device's "online status."
template <typename T>
struct Latest {
    T    msg;
    bool valid = false;
    void set(const T &m) { msg = m; valid = true; }
    void clear()         { valid = false; }
};

static Latest<CANFDMessage> g_sgx;      // FDCAN1  0x256
static Latest<CANFDMessage> g_tel;      // FDCAN1  0x18FF0CEB
static Latest<CANFDMessage> g_unkFd;    // FDCAN1  unknown
static Latest<CANMessage>   g_tamer;    // MCP2515 Li-ion Tamer
static Latest<CANMessage>   g_unkMcp;   // MCP2515 unknown

// The SEN66 deliberately does NOT use Latest<>: it produces exactly one frame per
// second, the same rate as the log cycle, so a clear-every-cycle flag would make the
// block appear and disappear as the two 1 Hz clocks drift past each other. Instead the
// last sample is kept with its timestamp and reported as STALE when it ages out.
struct Sen66Sample {
    float    pm1  = NAN, pm25 = NAN, pm4 = NAN, pm10 = NAN;
    float    rh   = NAN, tempC = NAN, voc = NAN, nox = NAN;
    uint16_t co2   = SEN66_CO2_INVALID;
    uint32_t stamp = 0;         // millis() when the frame was read
    bool     ever  = false;     // at least one valid frame has been received
};
static Sen66Sample g_sen66;

static enum : uint8_t { SEN66_RESET, SEN66_WAIT, SEN66_RUN } g_sen66State = SEN66_RESET;
static uint32_t g_sen66Timer = 0;
static char     g_sen66Err[48];

static float g_tjMax   = -273.0f;       // Max_temp
static float g_vddaMin = 99999.0f;      // Min_VDDA 

static unsigned long g_nextLog = 0;

static void pollAllCan();

// ======================= Setup Block =======================
static void setupSerial() {
    Serial.begin(115200);
    while (!Serial && millis() < 3000) {}
    Serial.println(F("A: boot"));
}

static void setupFdcan() {
    ACANFD_STM32_Settings fdSettings(CAN_BITRATE_T3650_SGXBLD2, DataBitRateFactor::x1, 32);
    const uint32_t err = fdcan1.beginFD(fdSettings);
    Serial.print(F("B: FDCAN1 beginFD = "));
    Serial.println(err);
}

static void setupMcp2515() {
    canSPI.begin();
    ACAN2515Settings mcpSettings(QUARTZ_FREQUENCY, CAN_BITRATE_TAMER);
    mcpSettings.mRequestedMode     = ACAN2515Settings::NormalMode;
    mcpSettings.mReceiveBufferSize = 32;

    const uint16_t err = can.begin(mcpSettings, [] { can.isr(); });
    if (err == 0) {
        Serial.println(F("C: MCP2515 OK"));
        Serial.print(F("   exact bit rate? "));
        Serial.println(mcpSettings.exactBitRate() ? F("yes") : F("no"));
        Serial.print(F("   sample point: "));
        Serial.print(mcpSettings.samplePointFromBitStart());
        Serial.println('%');
    } else {
        Serial.print(F("C: MCP2515 config error 0x"));
        Serial.println(err, HEX);
    }
}

static void setupSensors() {
    Wire.begin();
    Wire.setClock(100000);          // SEN66 ceiling; MICS is fine at this rate
    pinMode(ANALOG_IN_PIN, INPUT_ANALOG);
    analogReadResolution(12);       // Resolution in 12 bits
    Serial.println(F("D: sensors ok"));
}

// Only the reset is issued here. The 1.2 s settling time and the subsequent
// measurement start are handled by pollSen66() so that setup() stays short.
static void setupSen66() {
    sen66.begin(Wire, SEN66_I2C_ADDR_6B);

    const int16_t err = sen66.deviceReset();
    if (err != NO_ERROR) {
        errorToString(err, g_sen66Err, sizeof g_sen66Err);
        Serial.print(F("E: SEN66 reset failed: "));
        Serial.println(g_sen66Err);
    } else {
        Serial.println(F("E: SEN66 reset issued"));
    }

    // Serial number doubles as a bus-presence check. If your library version
    // declares getSerialNumber(char*, uint16_t), drop the (int8_t *) cast.
    char sn[32] = {0};
    if (sen66.getSerialNumber((int8_t *)sn, sizeof sn) == NO_ERROR) {
        Serial.print(F("   serial = "));
        Serial.println(sn);
    }

    g_sen66Timer = millis();
    g_sen66State = SEN66_RESET;
}

static void setupDieTemp() {
    // Drop some readings for warmup
    for (uint8_t i = 0; i < 8; i++) {
        (void)analogRead(ATEMP);
        (void)analogRead(AVREF);
        delay(5);
    }
    Serial.println(F("F: die-temp cal values"));
    Serial.print(F("   TS_CAL1  ( 30 C) = ")); Serial.println(*TS_CAL1_ADDR);
    Serial.print(F("   TS_CAL2  (130 C) = ")); Serial.println(*TS_CAL2_ADDR);
    Serial.print(F("   VREFINT_CAL      = ")); Serial.println(*VREFINT_CAL_ADDR);
}

void setup() {
    setupSerial();
    setupFdcan();
    setupMcp2515();
    setupSensors();
    setupSen66();
    setupDieTemp();
    Serial.println(F("G: setup done"));
    g_nextLog = millis() + LOG_INTERVAL;
}

// ======================= Collection =======================
static void pollFdcan() {
    CANFDMessage m;
    while (fdcan1.receiveFD0(m)) {          // Drain completely; FIFO to prevent backlog
        if      (m.id == ID_SGX)     g_sgx.set(m);
        else if (m.id == ID_TELAIRE) g_tel.set(m);
        else                         g_unkFd.set(m);
    }
}

static void pollMcp2515() {
    CANMessage f;
    while (can.receive(f)) {                // Drain completely; FIFO to prevent backlog
        const uint32_t pgn = (f.id >> 8) & 0x03FFFF;
        if (f.ext && pgn == PGN_TAMER && f.len >= 4) g_tamer.set(f);
        else                                         g_unkMcp.set(f);
    }
}

static void pollAllCan() {
    pollFdcan();
    pollMcp2515();
}

// Non-blocking SEN66 sequence: reset settle -> start -> first-frame delay -> 1 Hz reads.
// One read is ~2-3 ms of I2C traffic at 100 kHz, short enough that the FDCAN FIFO
// (32 slots) and the interrupt-driven MCP2515 buffer absorb anything that arrives.
static void pollSen66() {
    switch (g_sen66State) {

    case SEN66_RESET:
        if (millis() - g_sen66Timer < SEN66_RESET_MS) break;
        {
            const int16_t err = sen66.startContinuousMeasurement();
            g_sen66Timer = millis();                // retry in 1.2 s on failure
            if (err != NO_ERROR) {
                errorToString(err, g_sen66Err, sizeof g_sen66Err);
                Serial.print(F("SEN66 start failed: "));
                Serial.println(g_sen66Err);
                break;
            }
            g_sen66State = SEN66_WAIT;
        }
        break;

    case SEN66_WAIT:
        if (millis() - g_sen66Timer >= SEN66_WARMUP_MS) {
            g_sen66Timer = millis();
            g_sen66State = SEN66_RUN;
        }
        break;

    case SEN66_RUN:
        if (millis() - g_sen66Timer < SEN66_PERIOD_MS) break;
        // Advance by one period instead of reloading from millis(), so the sampling
        // instant does not drift with the ~100 ms that logData() spends on serial output.
        g_sen66Timer += SEN66_PERIOD_MS;
        if (millis() - g_sen66Timer > SEN66_PERIOD_MS) g_sen66Timer = millis();  // resync if badly late
        {
            Sen66Sample s;
            const int16_t err = sen66.readMeasuredValues(
                s.pm1, s.pm25, s.pm4, s.pm10, s.rh, s.tempC, s.voc, s.nox, s.co2);
            if (err == NO_ERROR) {
                s.stamp  = millis();
                s.ever   = true;
                g_sen66  = s;
            } else {
                errorToString(err, g_sen66Err, sizeof g_sen66Err);
                Serial.print(F("SEN66 read error: "));
                Serial.println(g_sen66Err);
            }
        }
        break;
    }
}

// Multiple samples are averaged to suppress ADC noise. The 200 µs interval between samples
// was originally idle time; here, it is repurposed to poll the CAN bus—averaging 16 samples
// across 2 channels takes about 6.4 ms, so the bus cannot be left unattended during this period.
static uint32_t readAvgPolled(uint32_t pin, uint8_t n) {
    uint32_t sum = 0;
    for (uint8_t i = 0; i < n; i++) {
        sum += analogRead(pin);
        const uint32_t t0 = micros();
        do { pollAllCan(); } while (micros() - t0 < 200);
    }
    return sum / n;
}

// ======================= Output =======================
static void printSeparator() {
    Serial.println(F("============================="));
}

static void logAdc() {
    const int sensorValue = analogRead(ANALOG_IN_PIN);
    Serial.print(F("Raw ADC Value: "));     // Start point for datalogger
    Serial.println(sensorValue);

    const float voltage = sensorValue * (3.3f / 4095.0f);
    Serial.print(F("Voltage: "));
    Serial.print(voltage, 3);
    Serial.println(F(" V"));
    printSeparator();
}

// Board-level health: Chip junction temperature (Tj) + actual VDDA.
// Tj refers to die temperature, not ambient temperature; factory calibration accuracy is approximately ±5°C,
// which is sufficient for determining whether overheating is occurring but cannot be used to log ambient temperature.
static void logDieTemp() {
    const uint32_t rawVref = readAvgPolled(AVREF, N_AVG);
    const uint32_t rawTs   = readAvgPolled(ATEMP, N_AVG);

    Serial.println(F("Board health (STM32G431KB):"));
    if (rawVref == 0) {  
        Serial.println(F("VREFINT read failed"));
        printSeparator();
        return;
    }

    // 1) Calculate the actual VDDA using the internal reference VREFINT: VREFINT voltage is constant; a lower reading implies a higher supply voltage
    const float vdda = CAL_VDDA * (float)(*VREFINT_CAL_ADDR) / (float)rawVref;

    // 2) Normalize the temperature channel readings to the 3.0 V reference used during calibration
    const float tsNorm = (float)rawTs * vdda / CAL_VDDA;

    // 3) Linear interpolation between two factory calibration points
    const float span = (float)(*TS_CAL2_ADDR) - (float)(*TS_CAL1_ADDR);
    const float tj   = (CAL_TEMP2 - CAL_TEMP1) / span
                       * (tsNorm - (float)(*TS_CAL1_ADDR)) + CAL_TEMP1;

    if (tj   > g_tjMax)   g_tjMax   = tj;
    if (vdda < g_vddaMin) g_vddaMin = vdda;

    Serial.print(F("Die Temp:           "));
    Serial.print(tj, 1);
    Serial.println(F(" C"));
    Serial.print(F("Die Temp Max:       "));
    Serial.print(g_tjMax, 1);
    Serial.println(F(" C"));
    Serial.print(F("VDDA:               "));
    Serial.print(vdda, 0);
    Serial.println(F(" mV"));
    Serial.print(F("VDDA Min:           "));
    Serial.print(g_vddaMin, 0);
    Serial.println(F(" mV"));
    Serial.print(F("ADC raw (ts/vref):  "));
    Serial.print(rawTs);
    Serial.print('/');
    Serial.println(rawVref);

    if (tj > TJ_ALARM)     Serial.println(F("Board Status:       OVERHEAT <<< INSPECTION NEEDED!"));
    else if (tj > TJ_WARN) Serial.println(F("Board Status:       HIGH"));
    else                   Serial.println(F("Board Status:       OK"));
    printSeparator();
}

// MICS CO2 is an equivalent value derived from the VOC channel, not a real CO2
// measurement; the SEN66 block below carries the NDIR reading.
static void logMics() {
    mics.readSensor();
    Serial.print(F("CO2 equ(ppm): "));
    Serial.print(mics.getCO2());
    Serial.println(F(" ppm"));
    Serial.print(F("VOC(isobutylene) equ: "));
    Serial.print(mics.getVOC());
    Serial.println(F(" ppb"));
    printSeparator();
}

// Prints "n/a" for NaN and for the SEN66 unknown-value sentinels, so an unavailable
// channel can never be mistaken for a real 6553.5 or 3276.7 reading.
static void printSen66Value(const __FlashStringHelper *label, float v, float invalid,
                            uint8_t dec, const __FlashStringHelper *unit) {
    Serial.print(label);
    if (isnan(v) || fabsf(v - invalid) < 0.05f) {
        Serial.println(F("n/a"));
        return;
    }
    Serial.print(v, dec);
    if (unit) { Serial.print(' '); Serial.print(unit); }
    Serial.println();
}

static void logSen66() {
    if (!g_sen66.ever) {
        Serial.print(F("SEN66: no valid frame yet ("));
        Serial.print(g_sen66State == SEN66_RUN ? F("running") : F("starting up"));
        Serial.println(F(")"));
        printSeparator();
        return;
    }

    const uint32_t age = millis() - g_sen66.stamp;

    Serial.println(F("Message received from SEN66:"));
    printSen66Value(F("PM1.0:              "), g_sen66.pm1,   SEN66_PM_INVALID,  1, F("ug/m3"));
    printSen66Value(F("PM2.5:              "), g_sen66.pm25,  SEN66_PM_INVALID,  1, F("ug/m3"));
    printSen66Value(F("PM4.0:              "), g_sen66.pm4,   SEN66_PM_INVALID,  1, F("ug/m3"));
    printSen66Value(F("PM10:               "), g_sen66.pm10,  SEN66_PM_INVALID,  1, F("ug/m3"));
    printSen66Value(F("Humidity:           "), g_sen66.rh,    SEN66_RHT_INVALID, 1, F("%"));
    printSen66Value(F("Temperature:        "), g_sen66.tempC, SEN66_RHT_INVALID, 2, F("C"));
    printSen66Value(F("VOC Index:          "), g_sen66.voc,   SEN66_IDX_INVALID, 1, nullptr);
    printSen66Value(F("NOx Index:          "), g_sen66.nox,   SEN66_IDX_INVALID, 1, nullptr);

    Serial.print(F("CO2:                "));
    if (g_sen66.co2 == SEN66_CO2_INVALID) Serial.println(F("n/a"));
    else { Serial.print(g_sen66.co2); Serial.println(F(" ppm")); }

    // The gas-index algorithms output a hard 0 until they have converged: VOC settles
    // toward 100 over tens of seconds, NOx toward 1 after roughly 10-15 s.
    if (g_sen66.voc == 0.0f || g_sen66.nox == 0.0f)
        Serial.println(F("SEN66 Status:       gas index warming up"));

    if (age > SEN66_STALE_MS) {
        Serial.print(F("SEN66 Status:       STALE, frame age "));
        Serial.print(age);
        Serial.println(F(" ms <<< CHECK I2C / POWER"));
    }
    printSeparator();
}

static void logSgxFlags(uint8_t flags) {
    if (flags == 0) {
        Serial.println(F("No status error"));
        return;
    }
    static const __FlashStringHelper *const NAMES[8] = {
        F(" Overvoltage:        "), F(" TC issue:           "),
        F(" RH issue:           "), F(" H2 out of range:    "),
        F(" Temperature issue:  "), F(" Undervoltage:       "),
        F(" Sensor replacement: "), F(" Low power bit:      ")
    };
    Serial.println(F("--- Flags ---"));
    for (uint8_t i = 0; i < 8; i++) {
        Serial.print(NAMES[i]);
        Serial.println((flags >> i) & 1);
    }
    Serial.println(F("-------------"));
}

static void logSgx() {
    if (!g_sgx.valid || g_sgx.msg.len < 7) return;
    const uint8_t *d = g_sgx.msg.data;

    Serial.println(F("Message received from SGX-BLD2:"));

    Serial.print(F("Temperature: "));
    Serial.print((int)d[0] - 55);
    Serial.println(F(" C"));

    const uint16_t h2_raw = ((uint16_t)d[1] << 8) | d[2];
    Serial.print(F("Hydrogen percent:   "));
    Serial.print(h2_raw * 0.01f, 2);
    Serial.println(F(" %"));

    logSgxFlags(d[3]);

    Serial.print(F("Voltage:            "));
    Serial.print(d[4] * 0.1f, 1);
    Serial.println(F(" V"));

    Serial.print(F("Humidity:           "));
    Serial.print(d[5] * 0.5f, 1);
    Serial.println(F(" %"));

    Serial.print(F("Roll Counter:       "));
    Serial.println(d[6] & 0x0F);
    Serial.print(F("Level CO:           "));
    Serial.println((d[6] >> 4) & 0x0F);
    printSeparator();
}

static void logTelaire() {
    if (!g_tel.valid || g_tel.msg.len < 8) return;
    const uint8_t *d = g_tel.msg.data;

    Serial.println(F("Message received from Telaire T3650:"));

    const uint16_t press_raw = ((uint16_t)d[1] << 8) | d[0];
    Serial.print(F("Pressure:           "));
    Serial.print(press_raw * 0.0078125f - 250.0f, 2);
    Serial.println(F(" kPa"));

    Serial.print(F("Humidity:  "));
    Serial.print(d[2] * 0.4f, 1);
    Serial.println(F(" %"));

    const uint16_t h2_raw = ((uint16_t)d[4] << 8) | d[3];
    Serial.print(F("H2 Concentration:   "));
    Serial.print(h2_raw * 0.0025f, 4);
    Serial.println(F(" %"));

    const uint16_t temp_raw = ((uint16_t)d[6] << 8) | d[5];
    Serial.print(F("Temperature:        "));
    Serial.print(temp_raw * 0.03125f - 273.0f, 2);
    Serial.println(F(" C"));

    Serial.print(F("Sensor Status:      0x"));
    Serial.println(d[7], HEX);
    printSeparator();
}

static void logTamer() {
    if (!g_tamer.valid) return;
    const CANMessage &f = g_tamer.msg;

    const uint8_t sa    = f.id & 0xFF;
    const uint8_t state = f.data[0];
    const int8_t  degC  = (int8_t)f.data[1];
    const int16_t raw   = (int16_t)((uint16_t)f.data[2] |
                                    ((uint16_t)f.data[3] << 8));
    const float   scalar = raw / 100.0f;

    static const char *const STATE_NAMES[] = {
        "Illegal", "Error", "Warmup", "Normal", "Alarm"
    };
    const char *stateName = (state <= 4) ? STATE_NAMES[state] : "Unknown";

    Serial.println(F("Message received from Li-ion Tamer:"));
    Serial.print(F("Tamer SA=0x"));   Serial.print(sa, HEX);
    Serial.print(F("  State="));      Serial.print(stateName);
    Serial.print(F("  Temp="));       Serial.print(degC);
    Serial.print(F("C  OffGas="));    Serial.print(scalar, 2);
    if (state == 4)          Serial.print(F("  <<< ALARM"));
    else if (scalar >= 1.0f) Serial.print(F("  (>= alarm trigger level)"));
    Serial.println();
    printSeparator();
}

static void logUnknownFrame(const char *bus, uint32_t id,
                            const uint8_t *data, uint8_t len) {
    Serial.print(F("Unknown device on "));
    Serial.print(bus);
    Serial.print(F("! ID=0x"));
    Serial.print(id, HEX);
    Serial.print(F(" Data="));
    for (uint8_t i = 0; i < len; i++) {
        Serial.print(data[i], HEX);
        Serial.print(' ');
    }
    Serial.println();
    printSeparator();
}

static void logData() {
    logAdc();
    logDieTemp();
    logMics();
    logSen66();
    logSgx();
    logTelaire();
    logTamer();
    if (g_unkFd.valid)
        logUnknownFrame("FDCAN1", g_unkFd.msg.id, g_unkFd.msg.data, g_unkFd.msg.len);
    if (g_unkMcp.valid)
        logUnknownFrame("MCP2515", g_unkMcp.msg.id, g_unkMcp.msg.data, g_unkMcp.msg.len);

    g_sgx.clear();
    g_tel.clear();
    g_tamer.clear();
    g_unkFd.clear();
    g_unkMcp.clear();
    // g_sen66 is intentionally not cleared; see the Sen66Sample declaration.
}

// ======================= Main Loop =======================
void loop() {
    pollAllCan();                                  // Always in mode
    pollSen66();                                   // 1 Hz I2C sampling, non-blocking

    if ((long)(millis() - g_nextLog) >= 0) {       // rollover safe
        g_nextLog += LOG_INTERVAL;
        logData();
        pollAllCan();                              // Capture to avoid missing
    }
}

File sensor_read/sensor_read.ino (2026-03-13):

#include <ACANFD_STM32.h>
#include <ACANFD_STM32_NUCLEO_G431KB-objects.h> 
#include <ACANFD_STM32_CANFDMessage.h>
#include <Wire.h>
#include "MICS-VZ-89TE.h"
MICS_VZ_89TE sensor;
#define MICS_ad 0x70
const int analogInPin = A0; 

void setup() {
    Serial.begin(115200);
    // CAN initialization
    ACANFD_STM32_Settings settings(500000, DataBitRateFactor::x1, 32); // 500kbps
    const uint32_t errorCode = fdcan1.beginFD(settings);
    if (errorCode == 0) {
        Serial.println("CAN Init OK");
    } else {
        Serial.print("CAN Init Error: ");
        Serial.println(errorCode);
    }

    // I2C initialization
    Wire.begin();

    // ADC Pin mode set
    pinMode(analogInPin, INPUT_ANALOG);
    analogReadResolution(12);
}

void loop() {
    delay(10000);
    // ADC part
    int sensorValue = analogRead(analogInPin);
    Serial.print("Raw ADC Value: ");
    Serial.println(sensorValue);

    float voltage = sensorValue * (3.3 / 4095.0);
    Serial.print("Voltage: ");
    Serial.print(voltage, 3); 
    Serial.println(" V");
    Serial.println("=============================");

    // I2C part
    sensor.readSensor();
    float co2 = sensor.getCO2();
    float voc = sensor.getVOC();
    uint32_t status = sensor.getStatus();
    uint32_t rev = sensor.getRev();
    Serial.print("CO2 equ(ppm): ");
    Serial.print(co2);
    Serial.println(" ppm");
    Serial.print("VOC(isobutylene) equ: ");
    Serial.print(voc);
    Serial.println(" ppb");
    Serial.println("=============================");

    // CAN part
    CANFDMessage msg;
    CANFDMessage rcvMsg;
    if (fdcan1.receiveFD0(rcvMsg)) {
        if (rcvMsg.id == 0x256){
            Serial.println("Message received from SGX-BLD2:");

            // 1 Temperature
            int temp_raw = rcvMsg.data[0];
            int temperature_phys = temp_raw - 55;
            Serial.print("Temperature: ");
            Serial.print(temperature_phys);
            Serial.println(" C");

            // 2 Hydrogen percent
            uint16_t h2_raw = (rcvMsg.data[1] << 8) | rcvMsg.data[2];
            float h2_phys = h2_raw * 0.01;
            Serial.print("Hydrogen percent:   ");
            Serial.print(h2_phys, 2);
            Serial.println(" %");

            // 3 Flags
            uint8_t flags_byte = rcvMsg.data[3];
            bool overvoltage       = (flags_byte >> 0) & 1;
            bool tc_issue          = (flags_byte >> 1) & 1;
            bool rh_issue          = (flags_byte >> 2) & 1;
            bool h2_out_of_range   = (flags_byte >> 3) & 1;
            bool temp_issue        = (flags_byte >> 4) & 1;
            bool undervoltage      = (flags_byte >> 5) & 1;
            bool sensor_replace    = (flags_byte >> 6) & 1;
            bool low_power_bit     = (flags_byte >> 7) & 1;
            if (flags_byte & 0xFF) {
                Serial.println("--- Flags ---");
                Serial.print(" Overvoltage:        "); Serial.println(overvoltage);
                Serial.print(" TC issue:           "); Serial.println(tc_issue);
                Serial.print(" RH issue:           "); Serial.println(rh_issue);
                Serial.print(" H2 out of range:    "); Serial.println(h2_out_of_range);
                Serial.print(" Temperature issue:  "); Serial.println(temp_issue);
                Serial.print(" Undervoltage:       "); Serial.println(undervoltage);
                Serial.print(" Sensor replacement: "); Serial.println(sensor_replace);
                Serial.print(" Low power bit:      "); Serial.println(low_power_bit);
                Serial.println("-------------");
            }
            else {
                Serial.println("No status error");
            }

            // 4 Voltage
            uint8_t voltage_raw = rcvMsg.data[4];
            float voltage_phys = voltage_raw * 0.1;
            Serial.print("Voltage:            ");
            Serial.print(voltage_phys, 1);
            Serial.println(" V");

            // 5 Humidity
            uint8_t humidity_raw = rcvMsg.data[5];
            float humidity_phys = humidity_raw * 0.5;
            Serial.print("Humidity:           ");
            Serial.print(humidity_phys, 1);
            Serial.println(" %");

            // 6 Roll counter
            uint8_t byte6 = rcvMsg.data[6];
            uint8_t roll_counter = byte6 & 0x0F;
            uint8_t level_co = (byte6 >> 4) & 0x0F;
            Serial.print("Roll Counter:       ");
            Serial.println(roll_counter);
            Serial.print("Level CO:           ");
            Serial.println(level_co);
            Serial.println("=============================");
        }

        else if (rcvMsg.id == 0x18FF0CEB){
            Serial.println("Message received from Telaire T3650:");

            // 1 Pressure
            uint16_t press_raw = (rcvMsg.data[1] << 8) | rcvMsg.data[0];
            float pressure = (press_raw * 0.0078125) - 250.0;   
            Serial.print("Pressure:           ");
            Serial.print(pressure, 2);
            Serial.println(" kPa");

            // 2 Humidity
            uint8_t h_raw = rcvMsg.data[2];
            float humidity = h_raw * 0.4;
            Serial.print("Humidity:  ");
            Serial.print(humidity, 1);
            Serial.println(" %");    

            // 3 H2 concentration
            uint16_t h2_raw = (rcvMsg.data[4] << 8) | rcvMsg.data[3];
            float h2_conc = h2_raw * 0.0025;
            Serial.print("H2 Concentration:   ");
            Serial.print(h2_conc, 4); 
            Serial.println(" %");

            // 4 Temperature
            uint16_t temp_raw = (rcvMsg.data[6] << 8) | rcvMsg.data[5];
            float temperature = (temp_raw * 0.03125) - 273.0;
            Serial.print("Temperature:        ");
            Serial.print(temperature, 2);
            Serial.println(" C");
            
            // 5 Sensor status
            int8_t status = rcvMsg.data[7];
            Serial.print("Sensor Status:      0x");
            Serial.println(status, HEX);
            Serial.println("=============================");
        }

        else{
            Serial.println("Unknown device!");
            Serial.print("CAN RX: ID=");
            Serial.print(rcvMsg.id, HEX);
            Serial.print("Data=");
            for (uint8_t i = 0; i < rcvMsg.len; i++) {
                Serial.print(rcvMsg.data[i], HEX);
                Serial.print(" ");
            }
            Serial.println("=============================");
        }
    }
}

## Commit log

2025-09-08 Update files
    [data2.xlsx, data3.xlsx, data4.xlsx]
2025-11-25 11.25 Update
    [data2.xlsx, data3.xlsx, data4.xlsx]
2026-02-24 Add sensor data logging functionality
    This script reads data from various sensors via a serial connection and logs the data to an Excel file. It handles data from internal sensors, SGX-BLD2, and Telaire T3650, saving entries periodically.
2026-03-13 Update of guides & PCB design
    [Connection.brd, Connection.sch, gas_data.csv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]
2026-03-24 Update design
    [Connection.brd, Connection.sch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]
2026-06-03 Upload PCB design pdf
2026-06-24 Updated designs
    [Connection.brd, Connection.sch, Connection_bottom_bom.csv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]
2026-08-24 Latest code with Li-ion Tamer and structure optimization.
    [Connection.brd, Connection.sch, Connection_bottom_bom.csv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]
2026-08-26 Updated the power structure
2026-08-26 Corrected Power Architecture SEN66
2026-09-03 Integrate Sensirion SEN66 into firmware, logger, and docs
    Firmware: add the SEN66 on the shared I2C bus, clamped to 100 kHz. Startup is
    non-blocking (RESET -> WAIT -> RUN state machine in pollSen66) so the reset
    settle and first-frame delays never stall either CAN bus, and the read deadline
    advances by a fixed period instead of reloading from millis() so sampling does
    not drift with serial output. The sample is kept with its timestamp and flagged
    STALE past 2.5 s rather than using a Latest<> slot, which would blink as the two
    1 Hz clocks drift past each other. Unknown-value sentinels (6553.5 / 327.67 /
    3276.7 / 0xFFFF) print as n/a so a dead channel cannot pass as a real reading.
    NO_ERROR is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
    [OffgasMonitor.ino, serial_logger.py]
2026-09-11 Add Arduino version config
